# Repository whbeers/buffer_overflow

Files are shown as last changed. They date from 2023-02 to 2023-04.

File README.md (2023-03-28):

# Buffer Overflow Drive Effect

This is a re-creation of the DOD Overdrive 250 / MXR Distortion+ op-amp drive circuit, as a first attempt at basic PCB design in [KiCAD](https://www.kicad.org/). 

The board is built on the ["Noise Floor"](https://github.com/whbeers/noise_floor) pedal platform, which provides basic power protection, audio IO, and a footswitch with LED indicator.

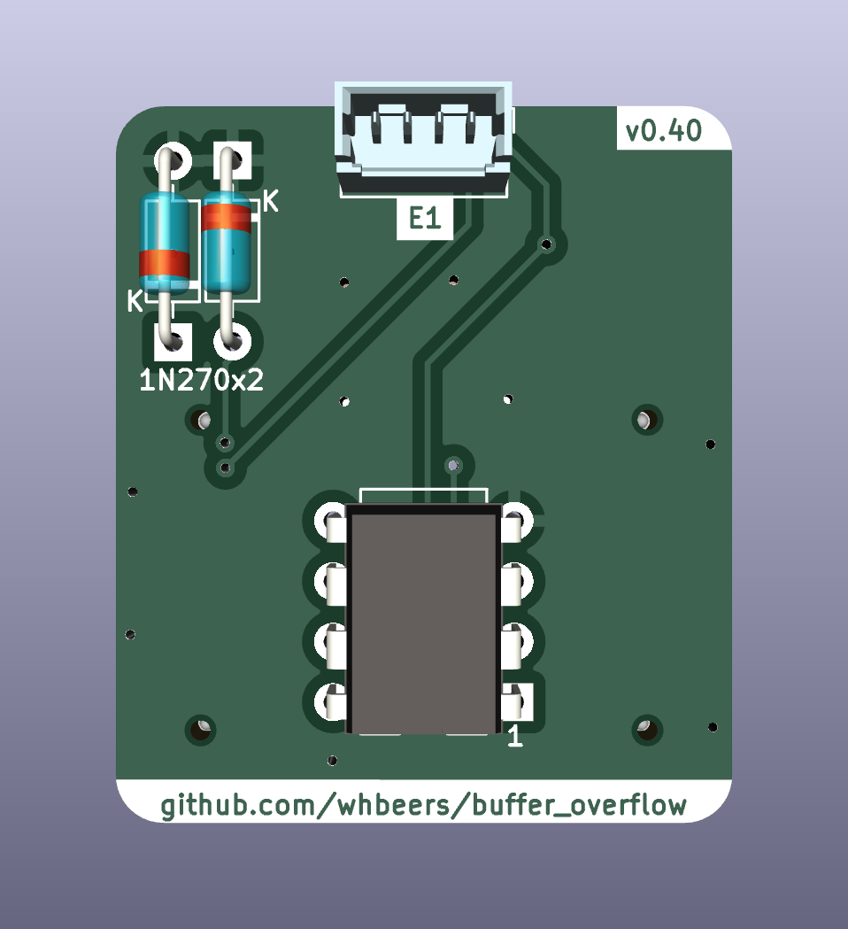
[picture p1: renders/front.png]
Front render

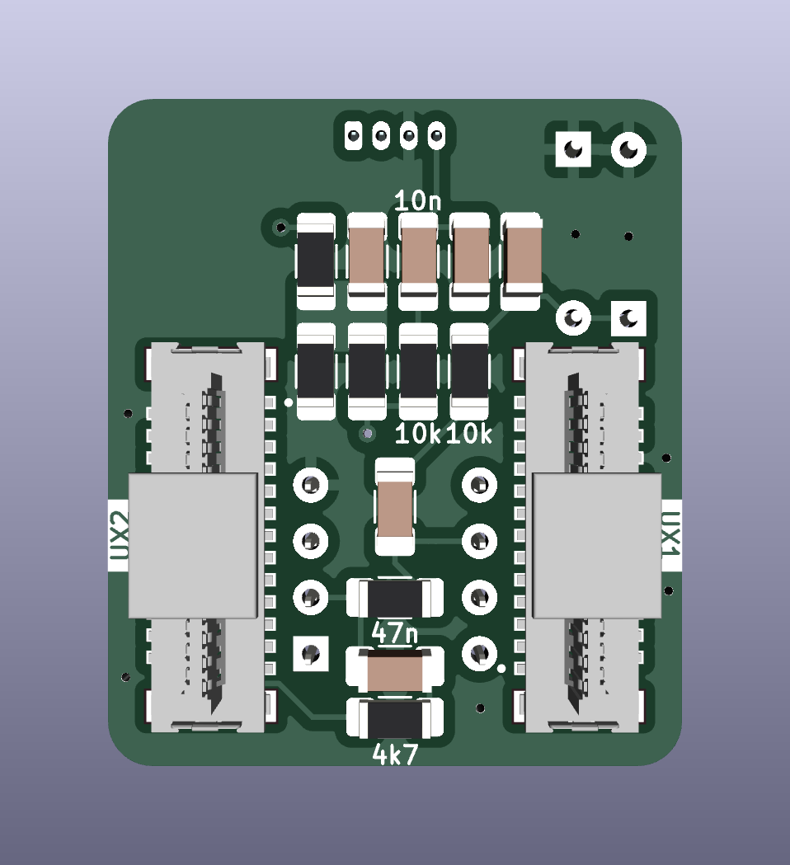
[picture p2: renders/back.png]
Back render

Schematic SVG
[Schematic PDF](schematics/buffer_overflow-latest.pdf)

## Credit
The basic schematic I worked from is available from a variety of sources, but this was primarily derived from the [PedalPCB Distortion 250](https://www.pedalpcb.com/product/dist250/). I strongly endorse PedalPCB (and this pedal) as a great way to get started building effects.

Thanks as always to the folks on the [freestompboxes.org](https://www.freestompboxes.org/) forum for feedback and suggestions.

Conan Lite footprints adapted from the 51-position footprints available from SnapEDA: [Header](https://www.snapeda.com/parts/10162582-1134151LF/Amphenol%20ICC%20(FCI)/view-part/), [Receptacle](https://www.snapeda.com/parts/10162581-3134151LF/Amphenol%20ICC%20(FCI)/view-part/).([Additional license details](hardware/SnapEDA_Licensing.txt)). 3D models courtesy Amphenol.

*I am not affiliated with any of the brands, sites, or products named in this overview.*

## Versioning

My pcb designs utilize the following versioning scheme (I'll add to this as I produce more revisions):
 - v0.0XX: A candidate design that has not yet been produced and tested.
 - v0.XX: A design that has been produced, tested, and any initial errors addressed.

## Note on v0.40

v0.40 updates Buffer Overflow as a proof-of-concept for the experimental [Noise Floor](https://github.com/whbeers/noise_floor) UX board, which uses board-to-board connectors to modularize the control surface the effect. While it only exercises two potentiometers from the UX board, I may expand use of it (e.g. switchable clipping diode banks, etc).

I've also changed resistors and capacitors to 1206 SMD parts. Due to the fact that the board-to-board assemblies are also surface mount, it meant moving almost all parts to the back of the board. This resulted in an awkward-looking layout, to say the least, and I expect it to evolve over time.

## Name
*The name "Buffer Overflow" is a reflection of the nature of the effect (an overdrive) and security nerdery.*

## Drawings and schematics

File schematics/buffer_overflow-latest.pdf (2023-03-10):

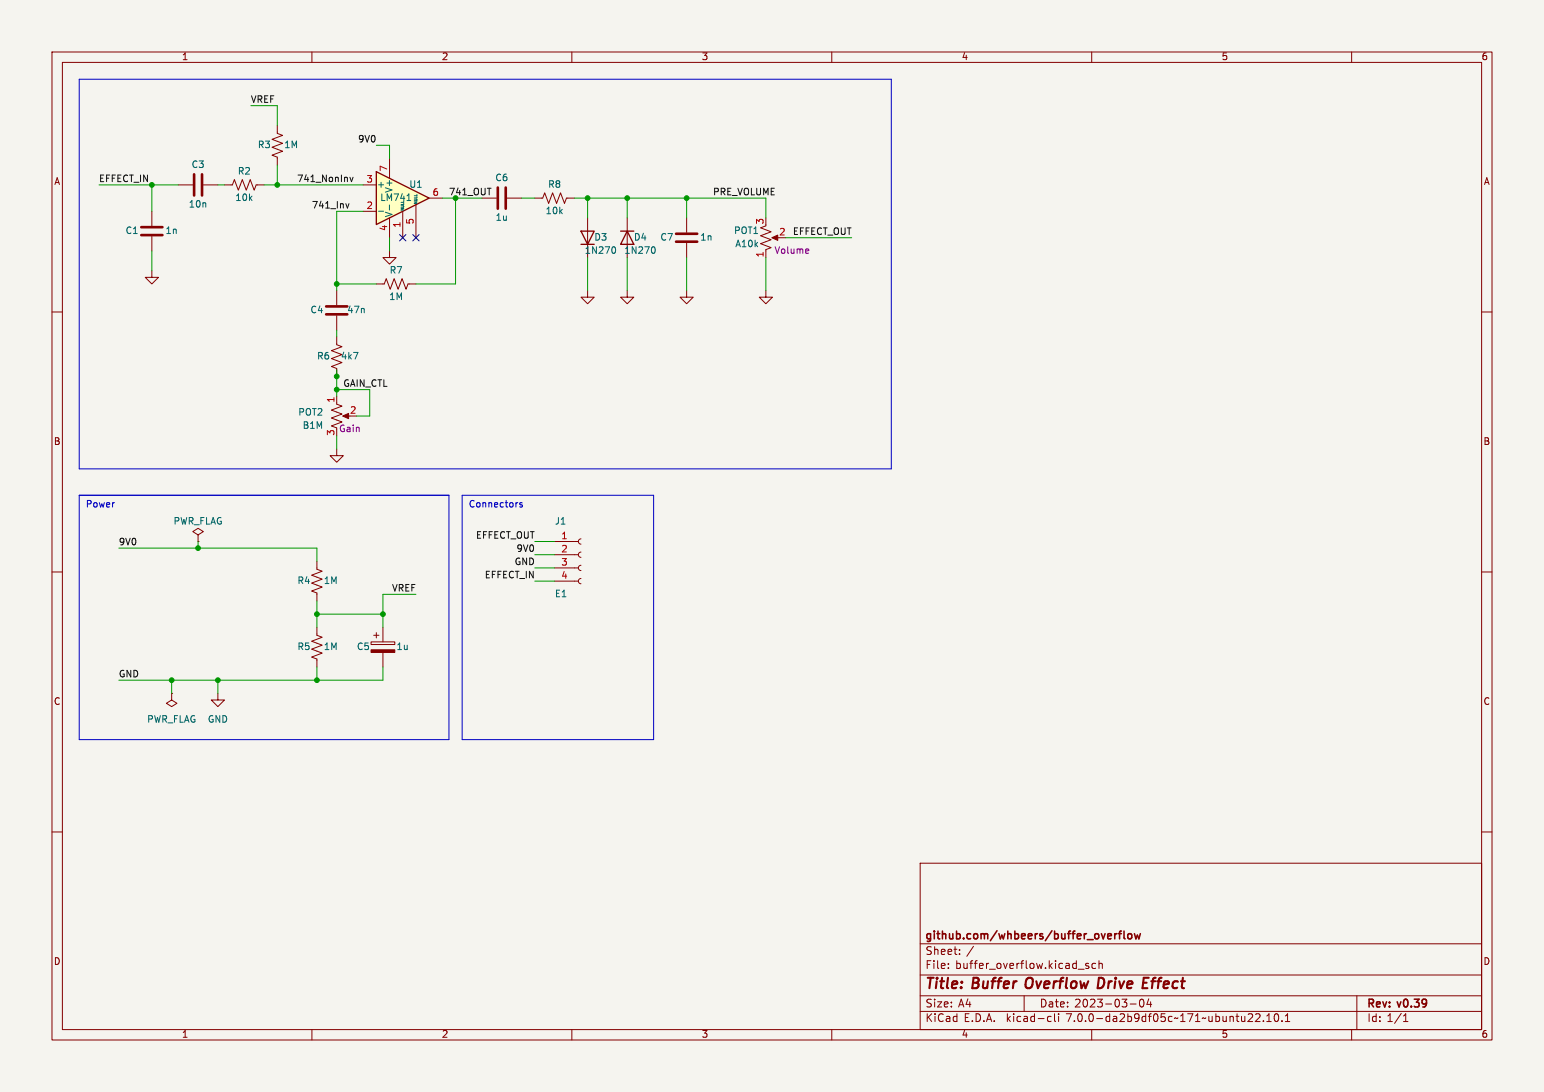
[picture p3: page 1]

Id: 1/1 Title: Buffer Overflow Drive Effect File: buffer_overflow.kicad_sch Sheet: / github.com/whbeers/buffer_overflow

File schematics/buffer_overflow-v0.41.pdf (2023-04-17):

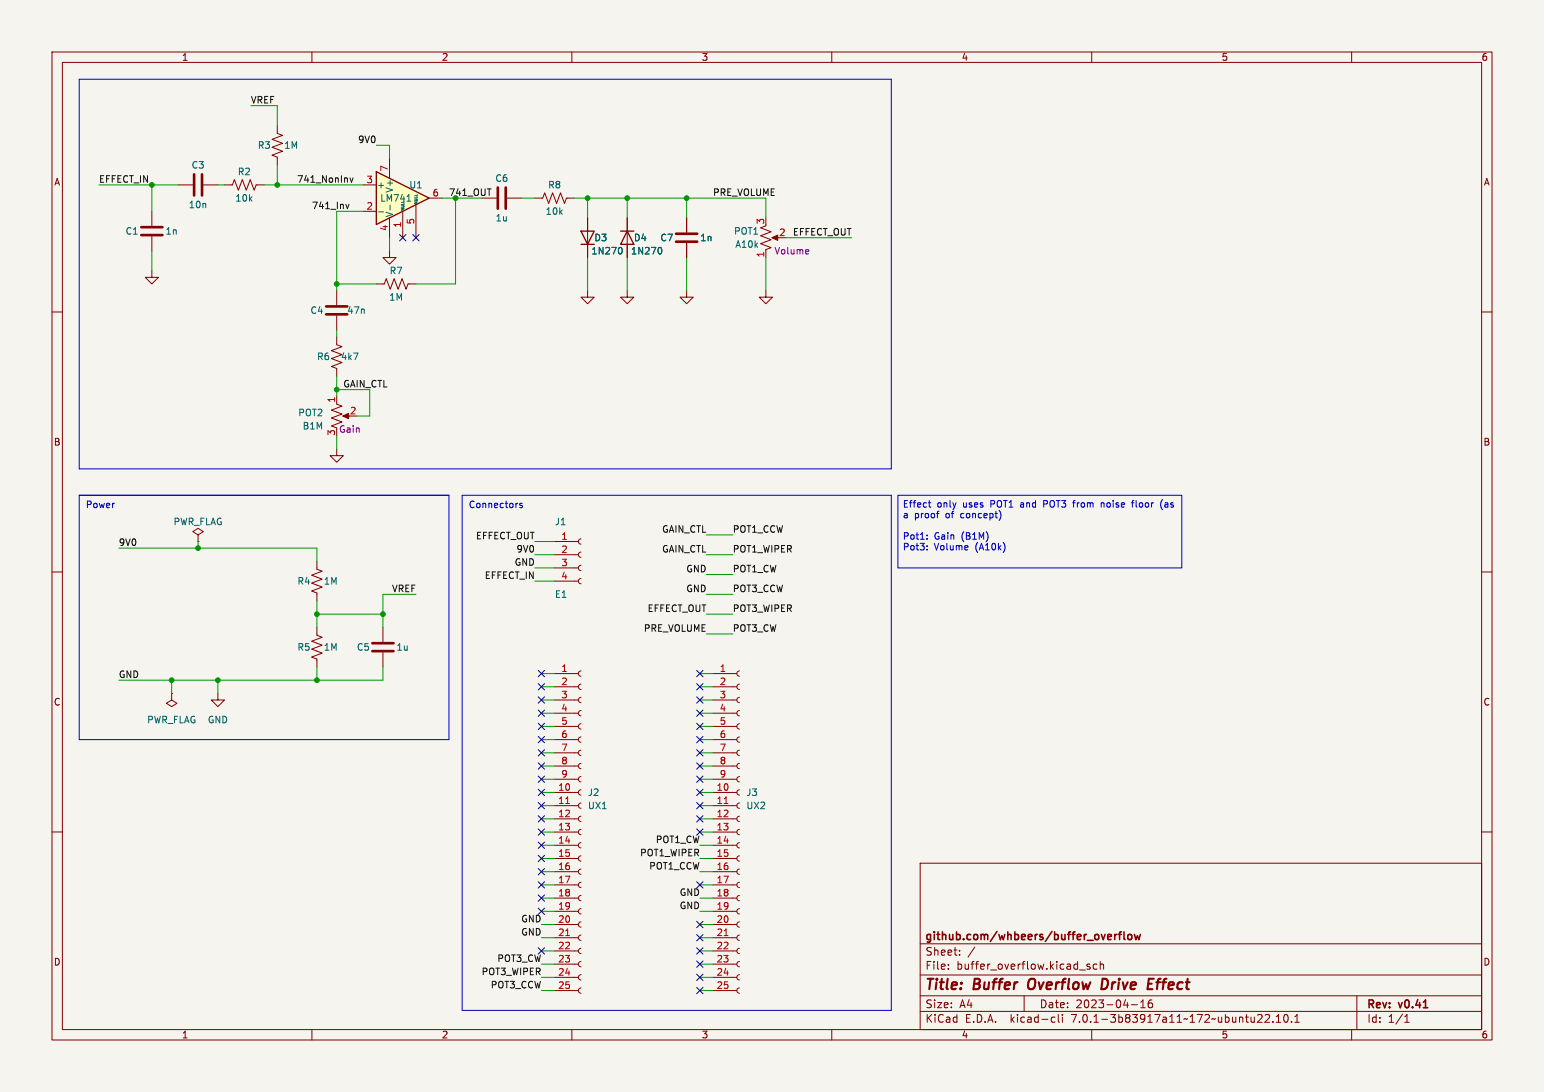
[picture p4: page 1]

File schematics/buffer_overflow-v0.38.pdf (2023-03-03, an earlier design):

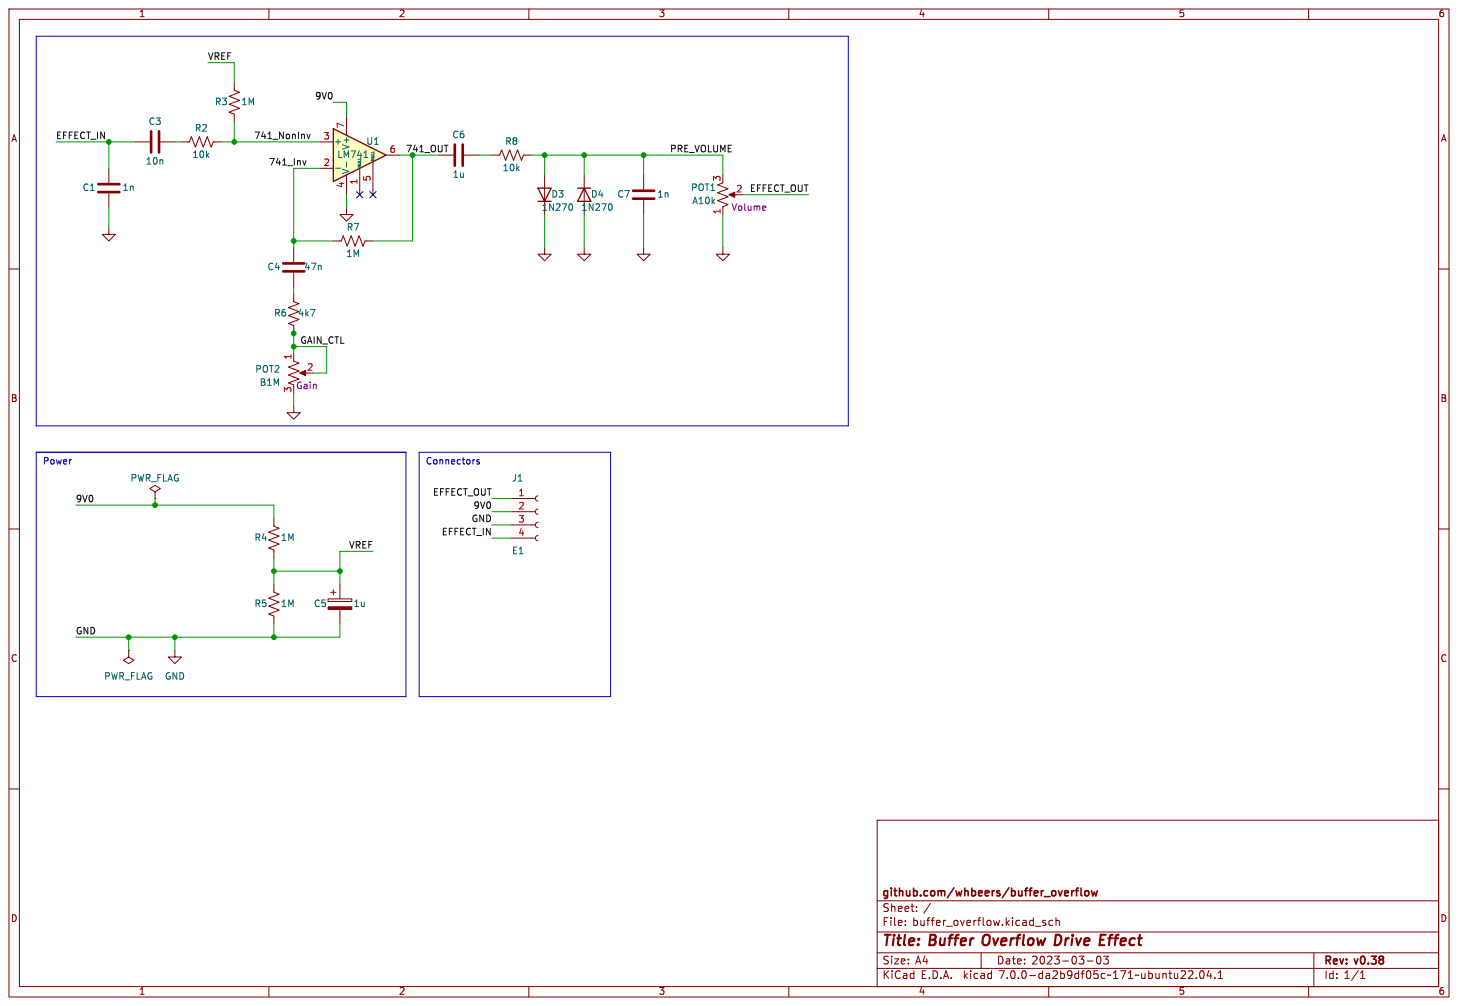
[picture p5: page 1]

Id: 1/1 Title: Buffer Overflow Drive Effect File: buffer_overflow.kicad_sch Sheet: / github.com/whbeers/buffer_overflow

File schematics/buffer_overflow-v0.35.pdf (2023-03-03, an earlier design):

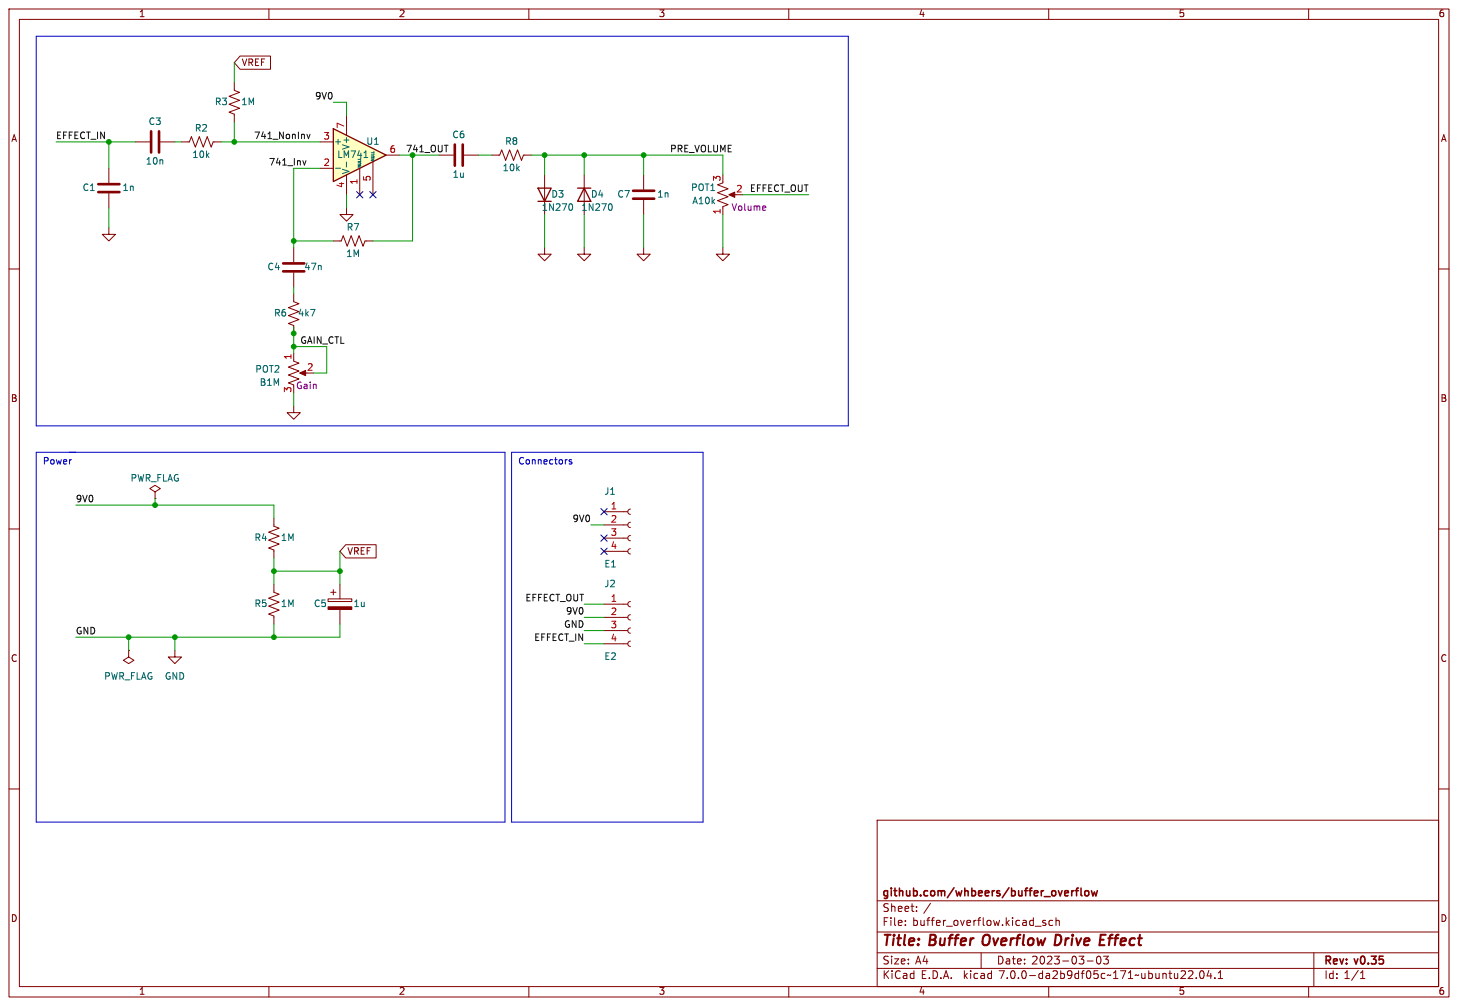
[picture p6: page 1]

Id: 1/1 Title: Buffer Overflow Drive Effect File: buffer_overflow.kicad_sch Sheet: / github.com/whbeers/buffer_overflow

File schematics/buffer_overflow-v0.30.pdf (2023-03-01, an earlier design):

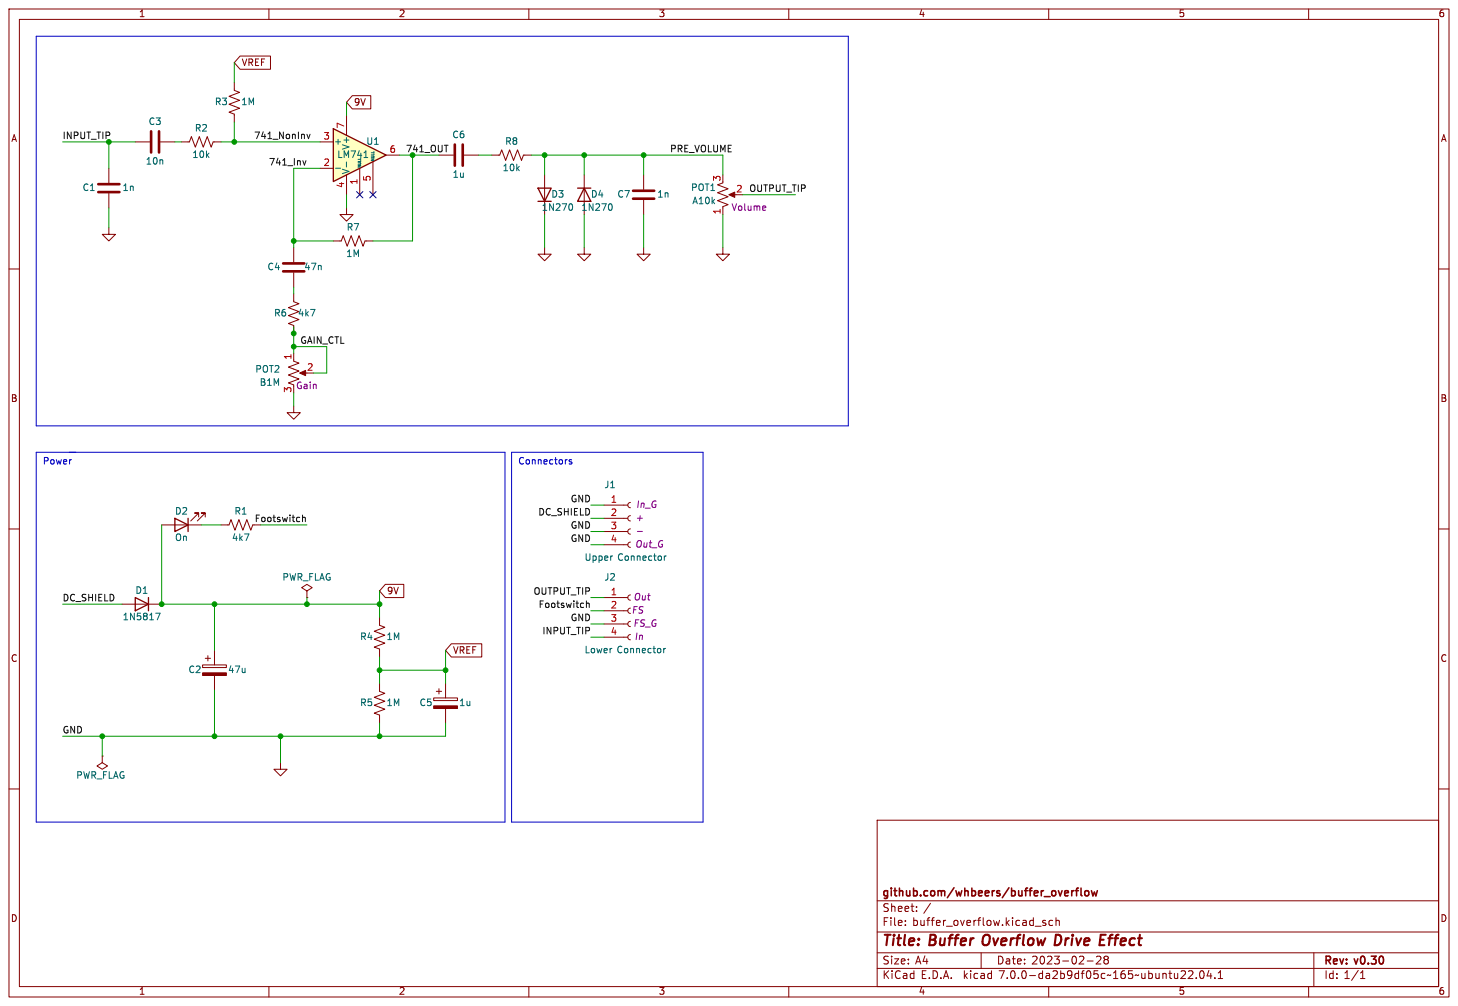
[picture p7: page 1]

Id: 1/1 Title: Buffer Overflow Drive Effect File: buffer_overflow.kicad_sch Sheet: / github.com/whbeers/buffer_overflow

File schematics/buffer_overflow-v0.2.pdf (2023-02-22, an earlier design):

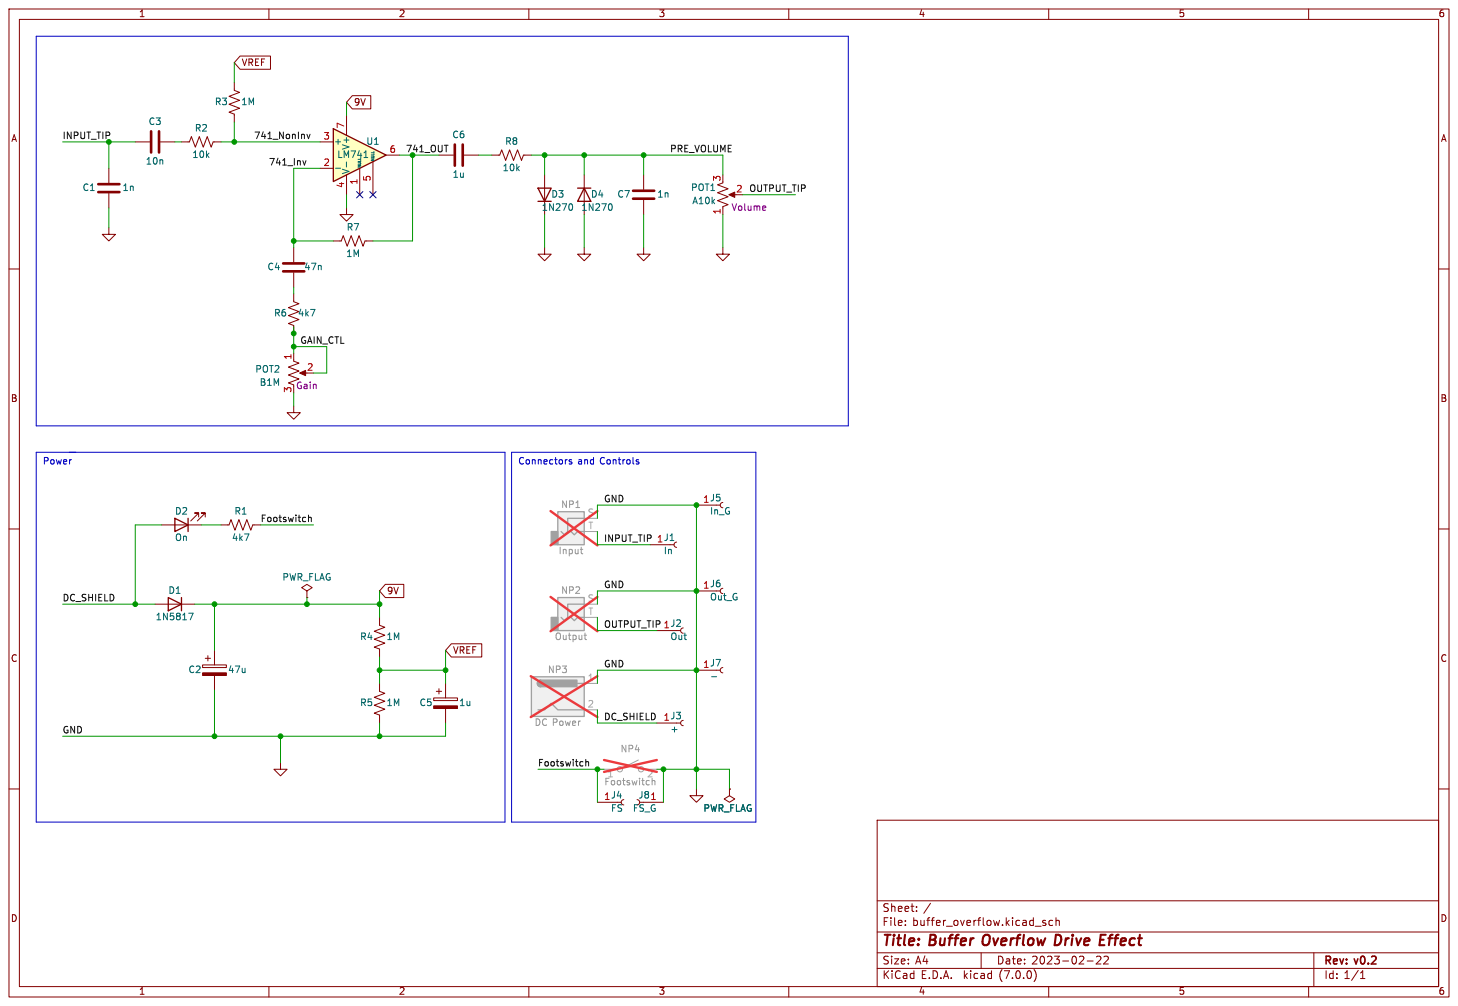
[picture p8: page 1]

Id: 1/1 Title: Buffer Overflow Drive Effect File: buffer_overflow.kicad_sch Sheet: /

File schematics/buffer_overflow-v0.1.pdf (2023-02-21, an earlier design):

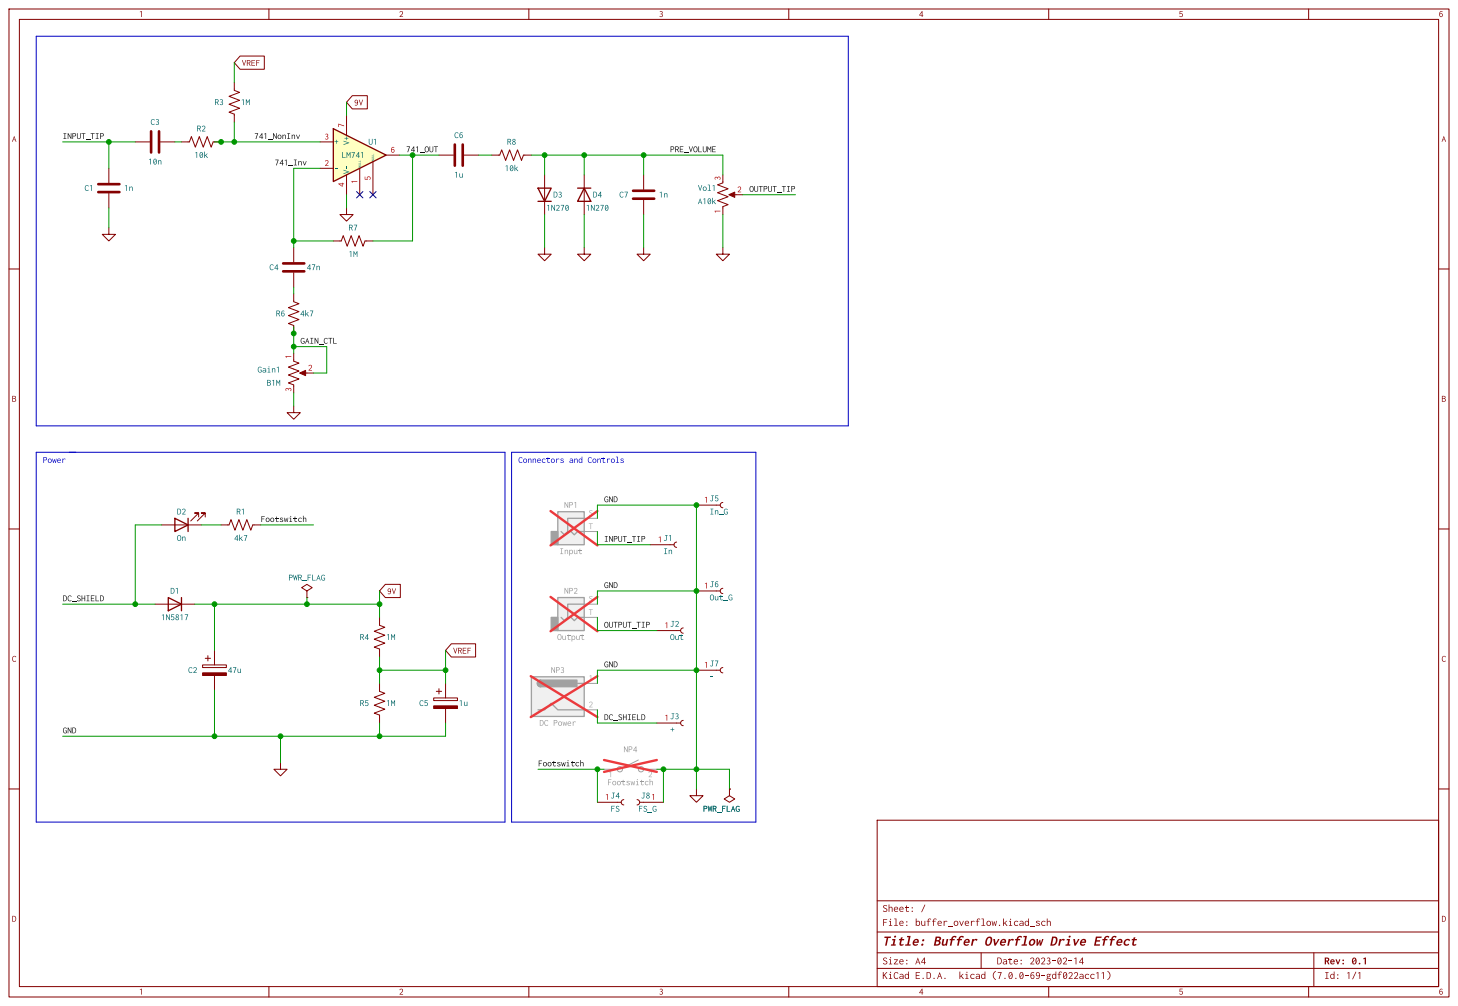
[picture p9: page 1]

Id: 1/1 Title: Buffer Overflow Drive Effect File: buffer_overflow.kicad_sch Sheet: / PWR_FLAG

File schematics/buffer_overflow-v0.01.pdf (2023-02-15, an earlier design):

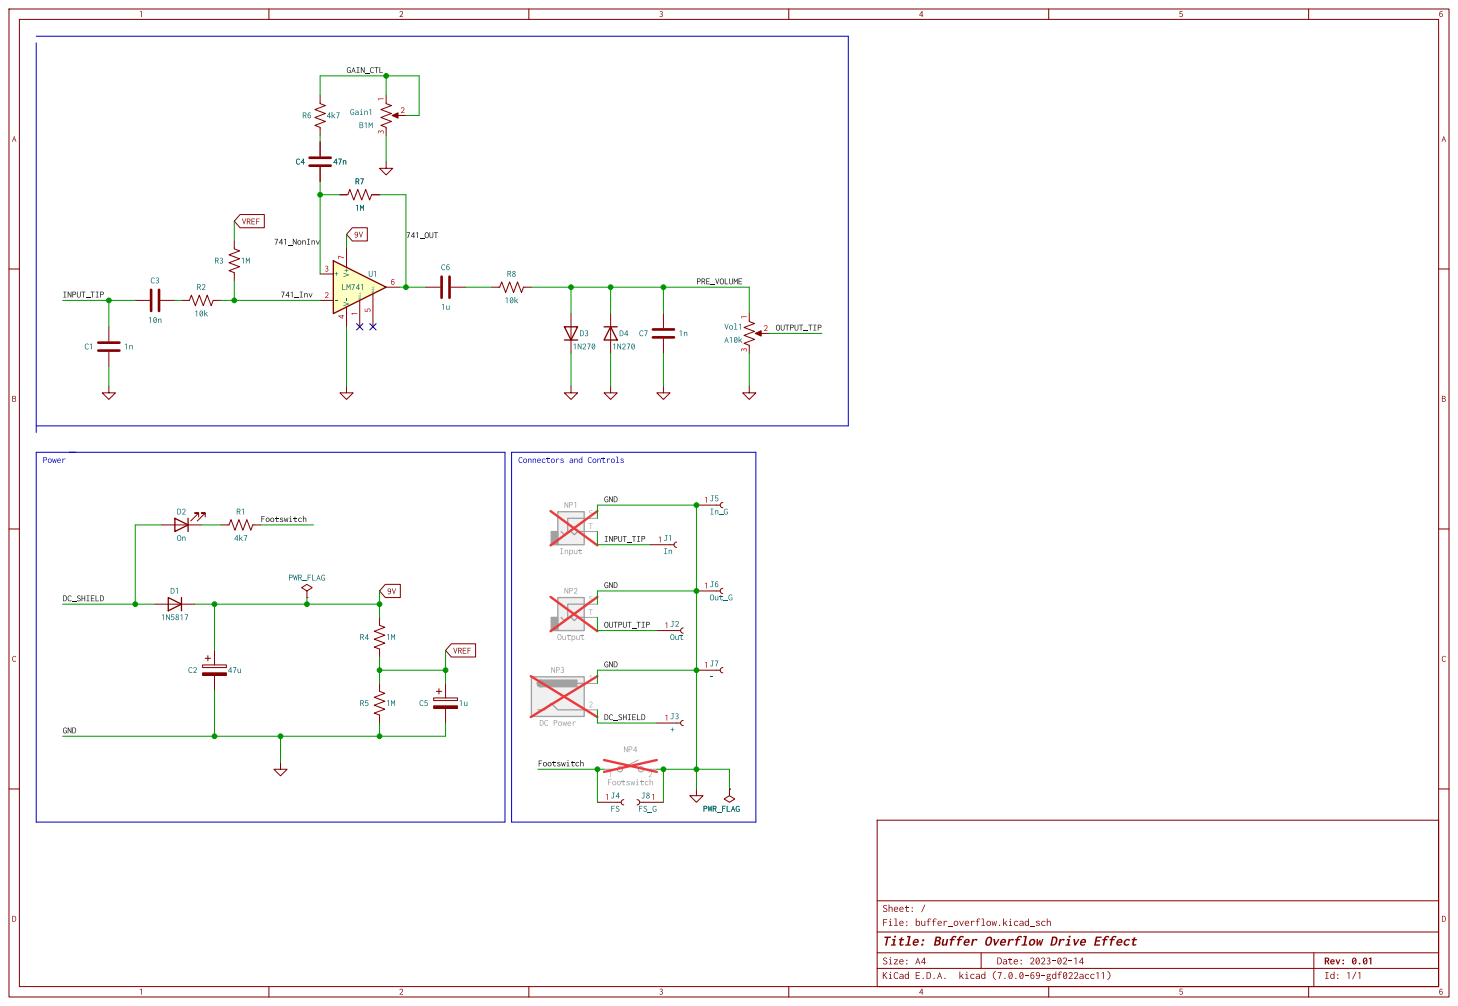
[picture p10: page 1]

Id: 1/1 Title: Buffer Overflow Drive Effect File: buffer_overflow.kicad_sch Sheet: / 1J7

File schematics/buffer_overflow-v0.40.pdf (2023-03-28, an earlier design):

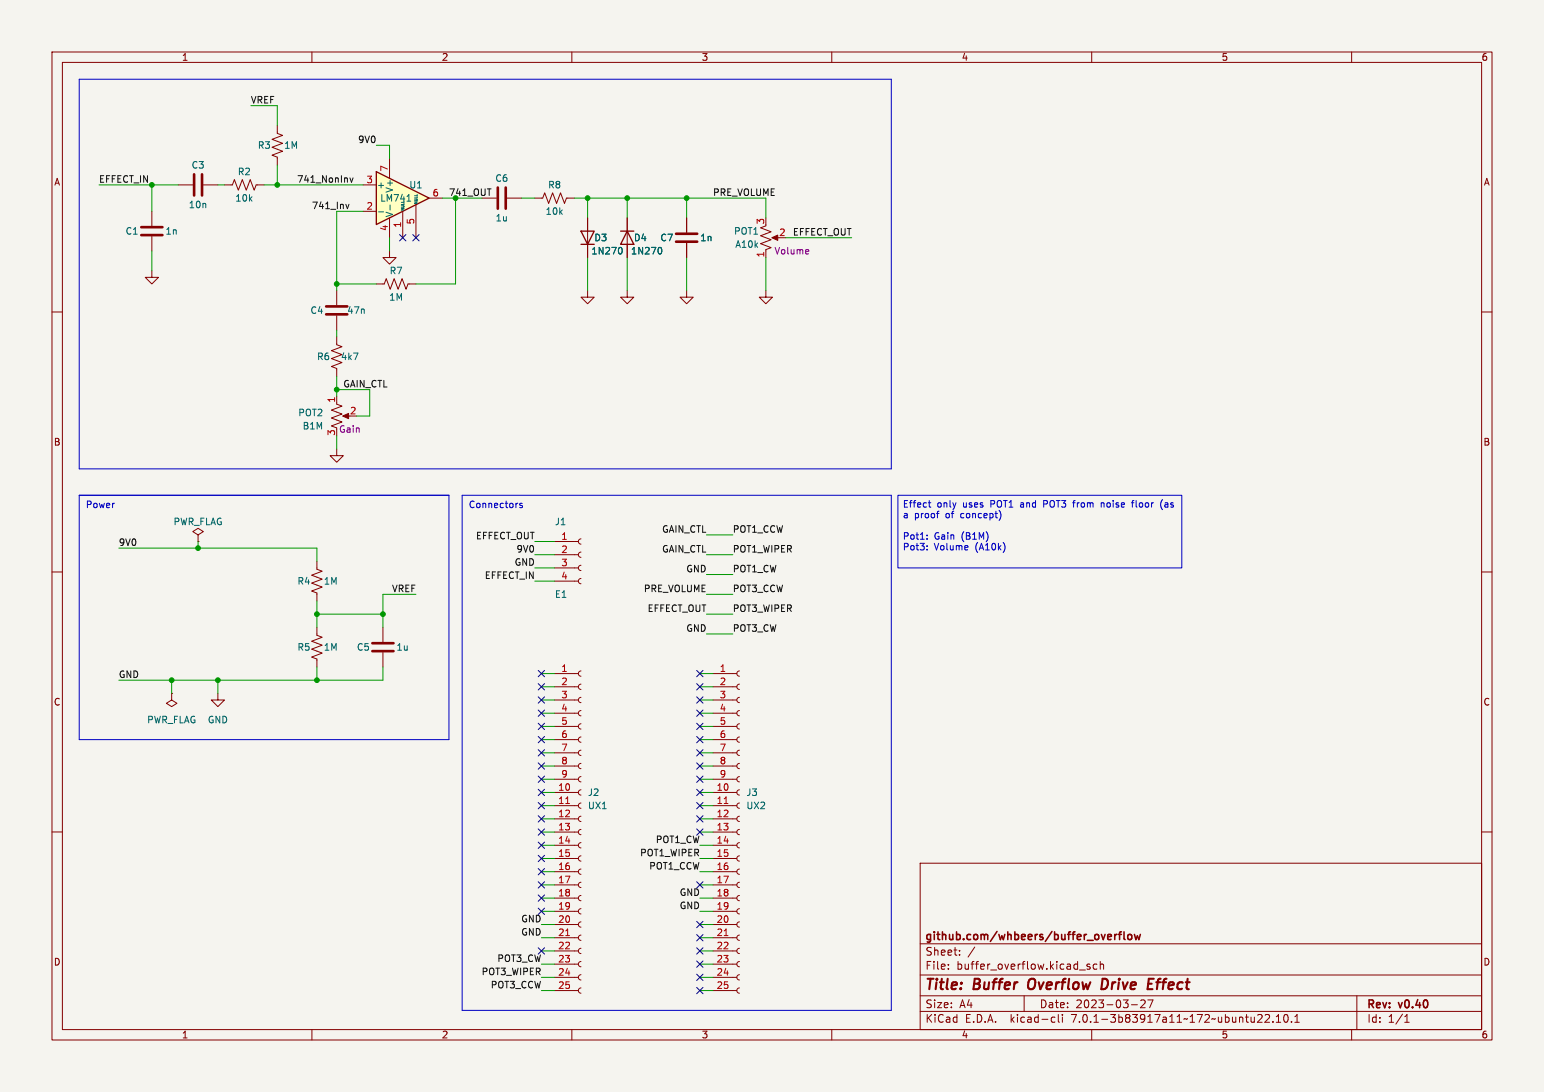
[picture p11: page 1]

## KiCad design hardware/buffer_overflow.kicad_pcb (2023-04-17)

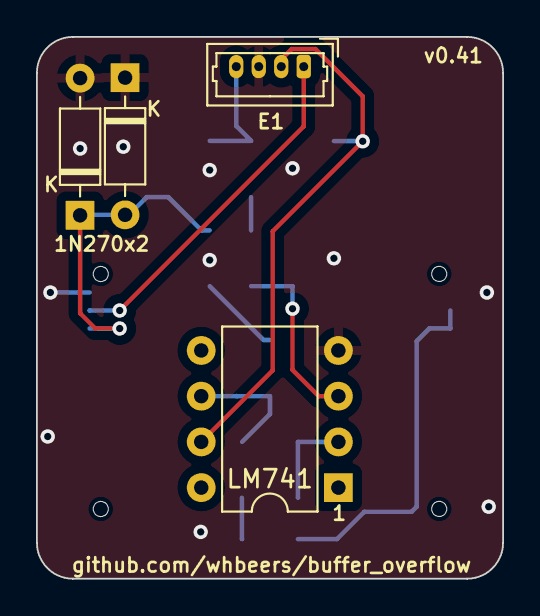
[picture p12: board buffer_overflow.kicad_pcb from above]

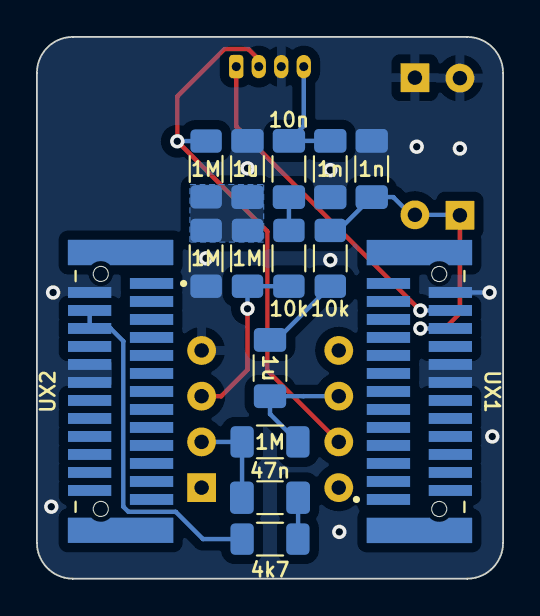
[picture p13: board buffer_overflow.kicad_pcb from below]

Board: 2 copper layers, 25.9 x 30.1 mm, 19 parts (15 on the bottom side), 13 nets.

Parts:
C1, C7: 1n; C_1206_3216Metric_Pad1.33x1.80mm_HandSolder
C3: 10n; C_1206_3216Metric_Pad1.33x1.80mm_HandSolder
C4: 47n; C_1206_3216Metric_Pad1.33x1.80mm_HandSolder
C5, C6: 1u; C_1206_3216Metric_Pad1.33x1.80mm_HandSolder
D3, D4: 1N270; D_DO-35_SOD27_P7.62mm_Horizontal
J1: E1; Molex_PicoBlade_53047-0410_1x04_P1.25mm_Vertical_with_3D_Mo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
J2: UX1; Amphenol_Header_25Pin_10162582-1134125LF
J3: UX2; Amphenol_Header_25Pin_10162582-1134125LF
R2, R8: 10k; R_1206_3216Metric_Pad1.30x1.75mm_HandSolder
R3, R4, R5, R7: 1M; R_1206_3216Metric_Pad1.30x1.75mm_HandSolder
R6: 4k7; R_1206_3216Metric_Pad1.30x1.75mm_HandSolder
U1: LM741; DIP-8_W7.62mm

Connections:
/9V0: J1.2, R4.2, U1.7 (V+)
/741_Inv: C4.2, R7.2, U1.2 (-)
/741_NonInv: R2.2, R3.1, U1.3 (+)
/741_OUT: C6.1, R7.1, U1.6
/EFFECT_IN: C1.2, C3.1, J1.4
/EFFECT_OUT: J1.1, J2.24
/GAIN_CTL: J3.15, J3.16, R6.2
/POT3_CW: C7.2, D3.2 (A), D4.1 (K), J2.23, R8.1
/VREF: C5.1, R3.2, R4.1, R5.2
GND: C1.1, C5.2, C7.1, D3.1 (K), D4.2 (A), J1.3, J2.20, J2.21, J2.25, J3.14, J3.18, J3.19, R5.1, U1.4 (V-)
unnamed: C3.2, R2.1
unnamed: C4.1, R6.1
unnamed: C6.2, R8.2

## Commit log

2023-02-15 add a non-lame schematic PDF
2023-02-15 todo on bom
2023-02-21 Fix issues identified in v0.01
    Bugfixes:
    - Reverse swapped opamp inputs
    - Reverse backwards Volume potentiometer
    Enhancements:
    - Cosmetic and functional updates to silkscreen
    - Include revision and github reference
    [buffer_overflow.kicad_pcb, buffer_overflow.kicad_sch]
2023-02-22 fix alignment of potentiometers
    [buffer_overflow.kicad_pcb]
2023-02-22 Mostly cosmetic updates
    - replace LED footprint with 3mm non-flat
    - shift text around
    - fix grid alignment for edge cuts
    - misc text updates
    [buffer_overflow.kicad_pcb, buffer_overflow.kicad_sch]
2023-02-22 add back surface finish
    [buffer_overflow.kicad_pcb]
2023-02-28 Address issues found in v0.1 hardware
    - cosmetic and usability changes
    [buffer_overflow.kicad_pcb]
2023-03-01 Updates for v0.30: - Replace wire connections with molex picoblade connectors - Many cosmetic changes and layout changes to reduce size and improve appearance
    [buffer_overflow.kicad_pcb, buffer_overflow.kicad_sch]
2023-03-01 Update README.md
    Eliminate claims that this is compatible with PedalPCB 3PDT adapters, now that I've switched to picoblade connectors.
2023-03-03 Offload functions of "noise floor" interface boards for v0.35
    - more layout changes coming, but functionality should be the same.
    [buffer_overflow.kicad_pcb, buffer_overflow.kicad_sch]
2023-03-03 condense and optimize layout
    [buffer_overflow.kicad_pcb]
2023-03-03 swap connectors to be on the same side as Noise Floor
    [buffer_overflow.kicad_pcb]
2023-03-03 condense to a single connector, bump rev to v0.38
    [buffer_overflow.kicad_pcb, buffer_overflow.kicad_sch]
2023-03-03 update schematic with correct identifier for E1
    [buffer_overflow.kicad_sch]
2023-03-04 Some updates based on feedback from freestompboxes.org folks:
    - Add back thermal reliefs on ground pads
    - Switch to stereo jacks for improved mechanical support
    - Add 3D models for various parts (courtesy of Vasily Kashirin - https://grabcad.com/vasily.kashirin-1/models?page=1)
    - Add more space between potentiometers (need to update the courtyard to make this more obvious in the future)
    [buffer_overflow.kicad_pcb, buffer_overflow.kicad_sch]
2023-03-04 fix a couple DRCs
    [buffer_overflow.kicad_pcb]
2023-03-05 add script to generate schematic, saving time at release. also embed an SVG schematic in README.
2023-03-05 add script to export gerbers and drill files
2023-03-10 update schematic plotting script to create the directory if it doesn't exist
2023-03-10 generate new schematic (although nothing should have updated)
2023-03-13 Update to latest stable kicad version:
    - fixed issue rendering certain 3d models in color
    - had to fix some text rendering changes
    [buffer_overflow.kicad_pcb]
2023-03-28 v0.40 - proof-of-concept for Noise Floor UX board
    - change to SMD resistors and capacitors
    - full re-layout and re-route to accomodate board-to-board assemblies
    [buffer_overflow.kicad_pcb, buffer_overflow.kicad_sch]
2023-04-17 Fix issue detected in hardware version v0.40
    - swap backwards volume knob pins
    [buffer_overflow.kicad_pcb, buffer_overflow.kicad_sch]
2023-04-17 update schematic
